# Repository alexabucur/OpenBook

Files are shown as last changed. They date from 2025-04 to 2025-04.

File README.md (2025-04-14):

# OpenBook



## Prezentare generala

Proiectul a fost realizat in cadrul disciplinei _Testarea Sistemelor de Calcul_ si isi propune crearea unui model 3D detaliat pentru o tableta E-Book Reader. Am proiectat atat la nivel de circuit, cat si la nivel de design al produsului, folosind programul _Fusion360_ de la Autodesk.

## Block Diagram


## Bill of Materials
| Device | Description | Datasheet | Price per Unit | Link |
|---|---|---|---|---|
| ADAFRUIT_LEDCHIP-LED0603 | LED | [datasheet](https://ro.mouser.com/datasheet/2/423/LSM0603412V-1379745.pdf) | 1,50 RON | [link](https://ro.mouser.com/ProductDetail/VCC/LSM0603412V?qs=sGAEpiMZZMt82OzCyDsLFG1ehM2%252BdxqbAopHlSxILTc%3D) |
| SJ | SMD solder JUMPER | [datasheet](https://www.farnell.com/datasheets/2813407.pdf) | 0,01 RON | [link](https://ro.farnell.com/panasonic/erj3gey0r00v/res-0r0-0-1w-0603-thick-film/dp/2059527) |
| ESP32_WROVER_EAGLE-LTSPICE_RR0402 | RESISTOR, European symbol | [datasheet](https://www.vishay.com/doc?28700) | 0,941 RON | [link](https://ro.mouser.com/ProductDetail/Vishay-Beyschlag/MCS04020D9101BE000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) |
| 112A-TAAR-R03_ATTEND | Micro SD Card Socket, Push-Push Type, Top Mount, SMT, H=1.83mm, 10u | [datasheet](https://www.attend.com.tw/data/download/file/112A-TAAR-R03.pdf) | 1,54 RON | [link](https://www.soselectronic.com/ro-ro/products/attend/112a-taar-r03-116052) |
| EAGLE-LTSPICE_CC0402 | CAPACITOR, European symbol | [datasheet](https://ro.mouser.com/datasheet/2/40/Accu_P-3077555.pdf) | 5,74 RON | [link](https://ro.mouser.com/ProductDetail/KYOCERA-AVX/04025J0R5ZBSTR?qs=k4kUdCzLgS7v2DzbDWDPRw%3D%3D) |
| ESP32_WROVER_SPARKFUN-DISCRETESEMI_MOSFET_PCH-DMG2305UX-7 | P-channel MOSFETs | [datasheet](https://www.diodes.com/assets/Datasheets/DMG2305UX.pdf) | 0,941 RON | [link](https://ro.mouser.com/ProductDetail/Diodes-Incorporated/DMG2305UX-7?qs=L1DZKBg7t5F%2FNBHrjfxC%252Bg%3D%3D) |
| 744043680IND_4828-WE-TPC_WRE | | [datasheet](https://www.we-online.com/components/products/datasheet/744043680.pdf) | 6,44 RON | [link](https://ro.mouser.com/ProductDetail/Wurth-Elektronik/744043680?qs=PGXP4M47uW6VkZq%252BkzjrHA%3D%3D)|
| BD5229G-TR | Voltage Detector with Adjustable Delay Time | [datasheet](https://datasheet.datasheetarchive.com/originals/distributors/Datasheets_SAMA/f2b9741ef86007909f138d561a359946.pdf) | 3,72 RON | [link](https://ro.mouser.com/ProductDetail/ROHM-Semiconductor/BD5229G-TR?qs=4kLU8WoGk0vvnhrrYwdszw%3D%3D) |
| CPH3225A | Cap 0.011F 3.3V 1210 Flat | [datasheet](https://ro.mouser.com/datasheet/2/360/Seiko_Instruments_MicroBattery_E_20230330_2024Jan_-3561061.pdf) | 11,04 RON | [link](https://ro.mouser.com/ProductDetail/Seiko-Semiconductors/CPH3225A?qs=3etwrb1wR%252BhUOph6lAO7eg%3D%3D) | 
| DS3231SN# | Real Time Clock Serial 16-Pin SOIC W T/R | [datasheet](https://ro.mouser.com/datasheet/2/609/DS3231-3421123.pdf) | 73,80 RON | [link](https://ro.mouser.com/ProductDetail/Analog-Devices-Maxim-Integrated/DS3231SN?qs=1eQvB6Dk1vhUlr8%2FOrV0Fw%3D%3D) |
| ESP32-C6-WROOM-1-N8 | | [datasheet](https://ro.mouser.com/datasheet/2/891/Espressif_ESP32_C6_WROOM_1__Datasheet_V0_1_PRELIMI-3239987.pdf) | 14,70 RON | [link](https://ro.mouser.com/ProductDetail/Espressif-Systems/ESP32-C6-WROOM-1-N8?qs=8Wlm6%252BaMh8ST02Gmwp74cw%3D%3D) |
| ESP32_WROVER_AVX---SD0805S020S1R0_AVX_ SD0805S020S1R0_0_0AVX_SD0805S020S1R0_0_0 | Schottky Barrier Rectifier Diode | [datasheet](http://datasheets.avx.com/schottky.pdf) | 1,46 RON | [link](https://ro.mouser.com/ProductDetail/KYOCERA-AVX/SD0805S020S1R0?qs=jCA%252BPfw4LHbpkAoSnwrdjw%3D%3D) |
| ESP32_WROVER_BME680_BME680 | Integrated Environmental Unit | [datasheet](https://ro.mouser.com/datasheet/2/783/BST_BME680_DS001-1509608.pdf) | 40,69 RON | [link](https://ro.mouser.com/ProductDetail/Bosch-Sensortec/BME680?qs=v271MhAjFHjo0yA%2FC4OnDQ%3D%3D) |
| ESP32_WROVER_SPARKFUN-IC-POWER_MCP73831 | MCP73831T Li-Ion, Li-Pol Controller | [datasheet](https://ro.mouser.com/datasheet/2/268/MCP73831_Family_Data_Sheet_DS20001984H-3441711.pdf) | 3,57 RON | [link](https://ro.mouser.com/ProductDetail/Microchip-Technology/MCP73831T-4ADI-OT?qs=hH%252BOa0VZEiBTiqxSV9eepQ%3D%3D) |
| FH34SRJ-24S-0.5SH_99_ |  (0.50mm) Surface Mount, Right Angle | [datasheet](https://ro.mouser.com/datasheet/2/185/FH34SRJ_24S_0_5SH_99__CL0580_1255_6_99_2DDrawing_0-1615044.pdf) | 12,87 RON | [link](https://ro.mouser.com/ProductDetail/Hirose-Connector/FH34SRJ-24S-0.5SH99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) |
| MAX17048G+T10 |  | [datasheet](https://ro.mouser.com/datasheet/2/609/MAX17048_MAX17049-3469099.pdf) | 21,19 RON | [link](https://ro.mouser.com/ProductDetail/Analog-Devices-Maxim-Integrated/MAX17048G%2bT10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) |
| MBR0530 | ON SEMICONDUCTOR - MBR0530 - DIODE, SCHOTTKY, 0.5A, 30V, SOD-123 | [datasheet](https://www.onsemi.com/PowerSolutions/product.do?id=MBR0530T3G) | 0,89 RON | [link](https://ro.mouser.com/ProductDetail/onsemi/MBR0530T3G?qs=3JMERSakebpEmdUS6GetdQ%3D%3D) |
| PGB1010603MR |  | [datasheet](https://www.littelfuse.com/assetdocs/pulseguard-esd-suppressors-pgb1-datasheet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) | 1,98 RON | [link](https://ro.mouser.com/ProductDetail/Littelfuse/PGB1010603MR?qs=gu7KAQ731URLg4GSnNNN7Q%3D%3D) |
| QWIIC_CONNECTORJS-1MM | SparkFun I2C Standard Qwiic Connector | [datasheet](https://ro.mouser.com/datasheet/2/813/Qwiic_Connector_Datasheet-1223982.pdf) | 2,75 RON | [link](https://ro.mouser.com/ProductDetail/SparkFun/PRT-14417?qs=wd5RIQLrsJhgdz%2FpmZ%2F3GQ%3D%3D) |
| SAMACSYS_PARTS_USB4110-GF-A | CONN USB 2.0 TYPE-C R/A SMT | [datasheet](https://ro.mouser.com/datasheet/2/837/GCT_USB4110_Product_Drawing___20k_cycles-3455479.pdf) | 5,84 RON | [link](https://ro.mouser.com/ProductDetail/GCT/USB4110-GF-A?qs=KUoIvG%2F9IlYiZvIXQjyJeA%3D%3D) |
| SI1308EDL-T1-GE3 | MOSFET N-Ch 30V 1.5A TrenchFET SC70 Vishay Si1308EDL-T1-GE3 N-channel MOSFET Transistor, 1.5 A, 30 V, 3-Pin SC-70 | [datasheet](https://www.vishay.com/doc?63399) | 2,07 RON | [link](https://ro.mouser.com/ProductDetail/Vishay-Semiconductors/SI1308EDL-T1-GE3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) |
| USBLC6-2SC6Y | Low Cap. ESD Protection Auto SOT-23-6 STMicroelectronics  | [datasheet](https://ro.mouser.com/datasheet/2/389/usblc6_2sc6y-1852505.pdf) | 2,16 RON | [link](https://ro.mouser.com/ProductDetail/STMicroelectronics/USBLC6-2SC6Y?qs=gNDSiZmRJS%2FOgDexvXkdow%3D%3D) |
| W25Q512JVEIQ |  | [datasheet](https://ro.mouser.com/datasheet/2/949/Winbond_W25Q512JV_Datasheet-3240039.pdf) | 28,91 RON | [link](https://ro.mouser.com/ProductDetail/Winbond/W25Q512JVEIQ?qs=l7cgNqFNU1jw6svr3at6tA%3D%3D) |
| XC6220A331MR-G | LDO Voltage Regulators | [datasheet](https://ro.mouser.com/datasheet/2/760/xc6220-3371556.pdf) | 7,23 RON | [link](https://ro.mouser.com/ProductDetail/Torex-Semiconductor/XC6220A331MR-G?qs=AsjdqWjXhJ8ZSWznL1J0gg%3D%3D) |

## Functionalitate hardware
Componentele principale ale circuitului sunt:

+ USB C Connector + ESD Protection
  
 > destinat alimentarii E-Book, se conecteaza prin interfata USB
 
+ SD Card
 
 > Secure Digital Card este folosit ca si mediu de stocare pentru cartile in format electronic; lucreaza la 3.3V si se conecteaza cu microcontrollerul prin interfata SPI
 
+ E-Paper Display, impreuna cu modulele aferente - E-Paper Drive Circuit, E-Paper Display Header, EPD Power
  
> EPD Header se conecteaza prin interfata SPI la microcontroller, si realizeaza legatura intre celelalte componente
> EPD Power furnizeaza tensiuni multiple, iar E-Paper Drive Circuit genereaza semnalele necesare pentru controlul display-ului E-Paper
>
> display-ul consuma cel mai mult la refresh, 30mA daca este alb-negru si pana la 60mA pentru display color, iar in modul inactiv, dupa ce a afisat imaginea, consumul este chiar zero
 
+ Environmental Sensor BME688
  
 > este un senzor de mediu ce poate masura temperatura, umiditatea, presiunea atmosferica si calitatea aerului, care functioneaza la 3.3V si se conecteaza prin interfata I2C
>
> are un consum redus, in standby sub 1uA, iar pentru masurare foloseste intre 1-2mA

+ RTC Module DS3231SN
  
 > este un modul Real-Time Clock care are rolul de a pastra data si ora curenta atunci cand microcontroller-ul este oprit; poate functiona pe baterie, si are un cristal de 32KHz integrat; se conecteaza la ESP32-C6 prin I2C, folosind pinii SCL si SDA
>
> consumul sau tipic variaza de la 150uA, atunci cand este alimentat de la sursa principala, si scade la 1uA la trecerea pe baterie

+ External NOR Flash 64MB
  
> extinde memoria microcontroller-ului, aici se stocheaza date suplimentare, se poate face si o stocare temporara; foloseste interfata SPI
> 
> contributia sa la consumul energetic total este foarte mica; cel mai mult se consuma la stergerea din flash (in jur de 50mA), respectiv la scriere (30-50mA); in standby se consuma numai 10-20uA

+	LDO Voltage Regulator
  
> este un stabilizator de tensiune liniar, care asigura tensiunea de iesire constanta la valoarea de 3.3V pentru microcontroller;
>
> are un consum energetic foarte mic (in jur de 8uA atunci cand este activ), ceea ce il face ideal pentru dispozitive alimentate pe baza de baterie, precum cel de fata

+ Voltage Supervisor
  
> folosit pentru monitorizeaza nivelului tensiunii, si pentru a asigura ca sistemul nu poate porni atunci cand avem o tensiune instabila sau mult prea mica

+ Qwiic/Stemma QT
  
> simplifica atasarea senzorilor si perifericelor la microcontroller, facand posibila conectarea mai multor dispozitive in lant, fara a fi nevoie de fire distincte pentru fiecare semnal; functioneaza pe baza protocolului I2C

+ Li-Po Battery Controller

> gestioneaza incarcarea/descarcarea bateriei, regland constant tensiunea si curentul;  la alimentarea bateriei, previne supraincarcarea , iar la descarcare monitorizeaza tensiunea pentru a evita descarcarea profunda; este conectat la sursa de alimentare si la baterie

## Microcontroller - ESP32-C6
Intreg circuitul a fost conceput in jurul microcontrollerului ESP32-C6-WROOM, care este un modul preasamblat, si principalul consumator energetic al circuitului. Consumul mediu se situeaza undeva intre 100uA si 2mA, avand in vedere ca in modul _Activ_ se consuma in jur de 100-120mA, in _Idle_ 10-15mA iar atunci cand se afla in _Deep Sleep_ doar 10-20uA. In mod evident, consumul depinde cel mai mult de durata sesiunilor active.
> Placa ESP-WROOM-32 dispune de o varietate de interfete pentru conectarea altor componente si senzori, inclusiv pini de I/O, SPI, I2C si UART. Aceastea faciliteaza integrarea si extind gama de aplicatii posibile. Placa foloseste WiFi 6 2.4 GHz, are integrat Bluetooth 5 si antena.
>> ESP32_C6
> ESP32-C6 se leaga de cele mai importante module ale circuitului prin intermediul pinilor sai:
> - **Alimentare si reset**
>> **3V3** asigura alimentrea modulului, **GND** legatura la masa, **EN** trebuie sa fie pe pozitia _HIGH_ pentru ca modulul sa functioneze (EN va fi controlat de catre butonul RESET)
> - **USB C Connector**
>> deoarece ESP32-C6 are USB nativ, conexiunea se realizeaza direct prin liniile de date **USB_D+** si **USB_D-**, la pinii **GPIO13** si **GPIO14** ai modulului; nu mai este deci nevoie de un convertor serial extern
> - **SD Card**
>> pentru a comunica cu dispozitive rapide precum SD Card se foloseste interfata SPI(Serial Peripheral Interface), folosind pinii **GPIO27(MISO)** - pentru transfer de la card la ESP, **GPIO7(MOSI)** - pentru transfer invers, **GPIO6(SCK)** -semnalul de ceas care asigura sincronizarea, respectiv **GPIO4(SS_SD)** - chip select
> - **E-Paper Display**
>> pentru conexiunea si controlul ecranului dispozitivului se folosesc pinii **GPIO11(EPD_CS)** - Chip Select pentru display-ul EPD, **GPIO5(EPD_DC)** - pentru controlul display-ului, **GPIO21(EPD_RST)** - pentru resetarea display-ului, respectiv **GPIO26(EPD_BUSY)**
> - **Environmental Sensor BME688**
>> avand in vedere ca se face comunicatia cu senzorul prin intermediul protocolului I2C, pentru stabilirea legaturii se vor folosi pinii **GPIO19(SDA)**, **GPIO20(SCL)** si **GPIO17(I2C_PW)** de pe microcontroller
> - **UART(Serial Communication)**
>> ESP32-C6 are si interfete seriale, utile pentru debugging sau conexiuni cu alte dispozitive; pinii aferenti comunicarii UART sunt **TXD0** -pentru transmisia datelor respectiv **RXD0** - pentru receptie de date
> - **Restul pinilor**
>> - **FLASH_CS** este un pin Chip Select pentru selectarea chipului flash extern (pentru comunicarea SPI cu External NOR Flash)
>> - **IO/BOOT** folosit pentru a intra in boot mode – legatura cu butonul de _boot_
>> - **RTC_PWM** pentru semnale Pulse Width Modulation trimise catre Real Time Clock
>> - **RTC_RST** pentru resetarea ceasului
>> - **INT_RTC** destinat semnalelor de intrerupere de la modulul RTC, de exemplu in cazul iesirii din moduri de functionare (sleep), pentru executarea unor sarcini periodice, cum ar fi un refresh al display-ului etc.

## Amplasarea componentelor / Reguli de design

La design-ul PCB-ului am tinut cont de cateva aspecte importante in ceea ce priveste amplasarea componentelor pe placuta. Astfel:

+ **Microcontroller-ul ESP32** se afla in marginea de sus a PCB-ului, cu antena inspre exterior si cu PCB-ul decupat in aceasta zona, pentru ca antena sa nu fie blocata si pentru a se evita orice interferente
+ **Conectorul USB** se afla in partea de jos a placutei, centrat astfel incat sa se alinieze cu orificiul din carcasa si sa permita conectarea mufei USB-C
+ **E-Paper Display Header** este pozitionat pe lateral, iar in dreptul sau exista un decupaj in PCB - acesta este spatiul in care se va introduce ribbon-ul display-ului nostru
+  **Conectorul Qwiic** e amplasat pe marginea PCB-ului, si s-a lasat suficient spatiu in jurul sau, pentru a permite conectarea facila a unor cabluri suplimentare
+  PCB-ul este decupat intr-o zona suficient de mare in care sa incapa si bateria device-ului
## Errors

La editarea PCB-ului in Fusion 360 am intampinat urmatoarele erori:
errors

Erorile au aparut din cauza dimensiunii gaurilor din mufa USB, asa ca le-am aprobat pe amandoua.

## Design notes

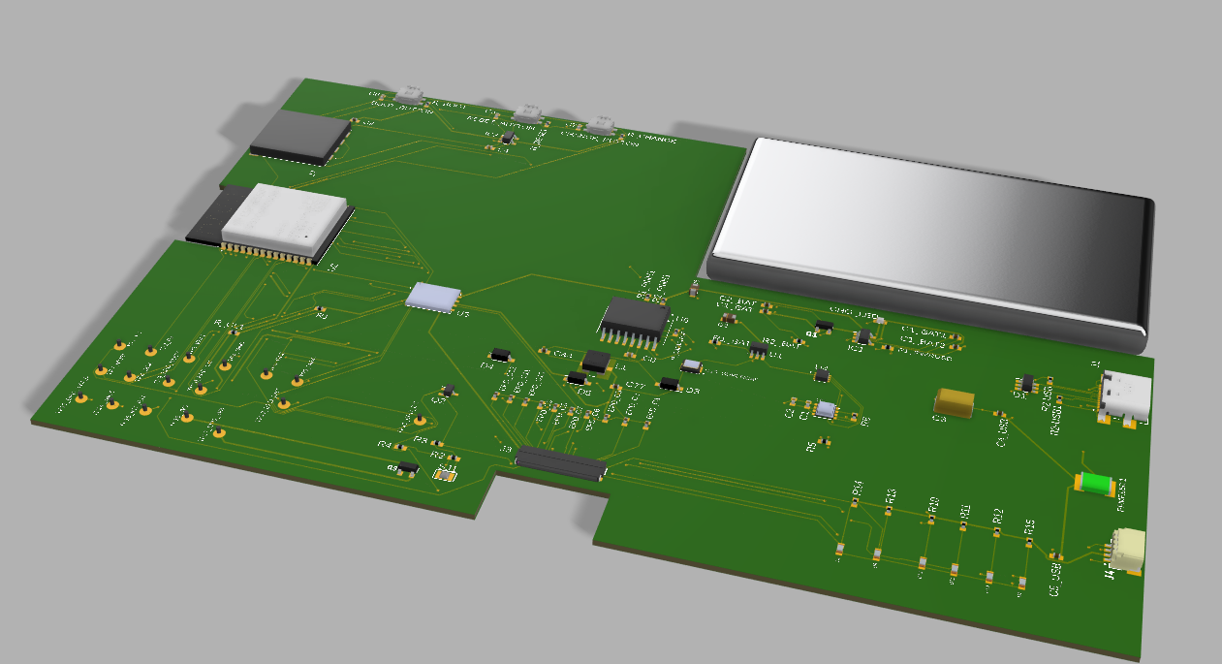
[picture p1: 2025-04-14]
Images/BoardRender.png

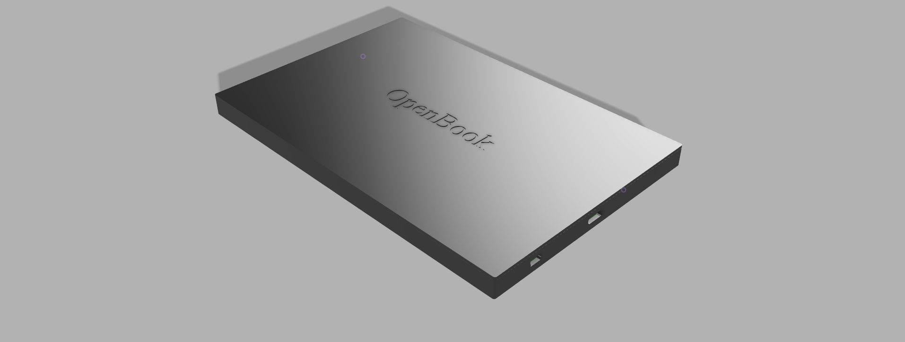
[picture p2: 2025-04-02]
Images/Device.png

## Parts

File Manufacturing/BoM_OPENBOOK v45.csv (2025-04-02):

Qty | Value | Device | Package | Parts | Description | ARROW_PART_NUMBER | ARROW_PRICE-STOCK | AVAILABILITY | CENTROID_NOT_SPECIFIED | CHECK_PRICES | COPYRIGHT | DATASHEET | DESCRIPTION | DIGIKEY_DESCRIPTION | DIGIKEY_PART_NUMBER | HEIGHT | LEAD_FREE | MANUFACTURER_NAME | MANUFACTURER_PART_NUMBER | MF | MFR_NAME | MOUSER_PART_NUMBER | MOUSER_PRICE-STOCK | MOUSER_TESTING_PART_NUMBER | MOUSER_TESTING_PRICE-STOCK | MP | MPN | PACKAGE | POPULARITY | PREFIX | PRICE | PROD_ID | PURCHASE-URL | ROHS | SNAPEDA_LINK | SPICEMODEL | SPICEPREFIX | TEMPERATURE_RANGE_HIGH | TEMPERATURE_RANGE_LOW | TP_SIGNAL_NAME | VALUE
1 |  | ADAFRUIT_LEDCHIP-LED0603 | ADAFRUIT_CHIP-LED0603 | CHG_LED | LED
1 |  | ESP32_WROVER_EAGLE-LTSPICE_RR0402 | ESP32_WROVER_EAGLE-LTSPICE_R0402 | R_CAPACITOR | RESISTOR, European symbol |  |  |  |  |  |  |  |  |  |  |  |  |  |  |  |  |  |  |  |  |  |  |  |  |  |  |  |  |  |  | NONE | R
1 |  | SJ | SJ | SJ1 | SMD solder JUMPER |  |  |  |  |  |  |  |  |  |  |  |  |  |  |  |  |  |  |  |  |  |  |  | 3
1 | 0.1uF/50V | EAGLE-LTSPICE_CC0402 | EAGLE-LTSPICE_C0402 | EPD_C5 | CAPACITOR, European symbol |  |  |  |  |  |  |  |  |  |  |  |  |  |  |  |  |  |  |  |  |  |  |  |  |  |  |  |  |  |  | NONE | C
1 | 0.47 | ESP32_WROVER_EAGLE-LTSPICE_RR0402 | ESP32_WROVER_EAGLE-LTSPICE_R0402 | R3 | RESISTOR, European symbol |  |  |  |  |  |  |  |  |  |  |  |  |  |  |  |  |  |  |  |  |  |  |  |  |  |  |  |  |  |  | NONE | R
1 | 100K | ESP32_WROVER_EAGLE-LTSPICE_RR0402 | ESP32_WROVER_EAGLE-LTSPICE_R0402 | R1_PWRUSB | RESISTOR, European symbol |  |  |  |  |  |  |  |  |  |  |  |  |  |  |  |  |  |  |  |  |  |  |  |  |  |  |  |  |  |  | NONE | R
8 | 100nF | EAGLE-LTSPICE_CC0402 | EAGLE-LTSPICE_C0402 | C1, C2, C4, C4_USB, C6, C7, C8, C9 | CAPACITOR, European symbol |  |  |  |  |  |  |  |  |  |  |  |  |  |  |  |  |  |  |  |  |  |  |  |  |  |  |  |  |  |  | NONE | C
1 | 100uF | RCL_CPOL-EUCT3528 | RCL_CT3528 | C3 | POLARIZED CAPACITOR, European symbol |  |  |  |  |  |  |  |  |  |  |  |  |  |  |  |  |  |  |  |  |  |  |  | 0 |  |  |  |  |  |  |  | C
16 | 10K | ESP32_WROVER_EAGLE-LTSPICE_RR0402 | ESP32_WROVER_EAGLE-LTSPICE_R0402 | R1, R1_PINH1, R2_PINH1, R4, R5, R6, R10, R11, R12, R13, R14, R15, R_BOOT, R_CHANGE, R_CL1, R_RESET | RESISTOR, European symbol |  |  |  |  |  |  |  |  |  |  |  |  |  |  |  |  |  |  |  |  |  |  |  |  |  |  |  |  |  |  | NONE | R
1 | 10uF | EAGLE-LTSPICE_CC0402 | EAGLE-LTSPICE_C0402 | C77 | CAPACITOR, European symbol |  |  |  |  |  |  |  |  |  |  |  |  |  |  |  |  |  |  |  |  |  |  |  |  |  |  |  |  |  |  | NONE | C
1 | 112A-TAAR-R03_ATTEND | 112A-TAAR-R03_ATTEND | 112ATAARR03ATTEND | J2 | Micro SD Card Socket, Push-Push Type, Top Mount, SMT, H=1.83mm, 10u |  |  |  |  |  |  |  | Micro SD Card Socket | Push-Push Type | Top Mount | SMT | H=1.83mm | 10u |  |  | 1.9mm |  | ATTEND | 112A-TAAR-R03 ATTEND
1 | 1uF | EAGLE-LTSPICE_CC0402 | EAGLE-LTSPICE_C0402 | C5 | CAPACITOR, European symbol |  |  |  |  |  |  |  |  |  |  |  |  |  |  |  |  |  |  |  |  |  |  |  |  |  |  |  |  |  |  | NONE | C
9 | 1uF/50V | EAGLE-LTSPICE_CC0402 | EAGLE-LTSPICE_C0402 | EPD_C1, EPD_C2, EPD_C6, EPD_C7, EPD_C8, EPD_C9, EPD_C10, EPD_C11, EPD_C12 | CAPACITOR, European symbol |  |  |  |  |  |  |  |  |  |  |  |  |  |  |  |  |  |  |  |  |  |  |  |  |  |  |  |  |  |  | NONE | C
1 | 2.2 | ESP32_WROVER_EAGLE-LTSPICE_RR0402 | ESP32_WROVER_EAGLE-LTSPICE_R0402 | R2 | RESISTOR, European symbol |  |  |  |  |  |  |  |  |  |  |  |  |  |  |  |  |  |  |  |  |  |  |  |  |  |  |  |  |  |  | NONE | R
1 | 200 | ESP32_WROVER_EAGLE-LTSPICE_RR0402 | ESP32_WROVER_EAGLE-LTSPICE_R0402 | R1_BAT | RESISTOR, European symbol |  |  |  |  |  |  |  |  |  |  |  |  |  |  |  |  |  |  |  |  |  |  |  |  |  |  |  |  |  |  | NONE | R
2 | 20V/4.2A/52mO/1.4W | ESP32_WROVER_SPARKFUN-DISCRETESEMI_MOSFET_PCH-DMG2305UX-7 | ESP32_WROVER_SPARKFUN-DISCRETESEMI_SOT23-3 | Q1, Q3 | P-channel MOSFETs |  |  |  |  |  |  |  |  |  |  |  |  |  |  |  |  |  |  |  |  |  |  |  |  |  |  | TRAN-14388 |  |  |  |  |  |  |  |  | 20V/4.2A/52mO/1.4W
1 | 2K | ESP32_WROVER_EAGLE-LTSPICE_RR0402 | ESP32_WROVER_EAGLE-LTSPICE_R0402 | R2_BAT | RESISTOR, European symbol |  |  |  |  |  |  |  |  |  |  |  |  |  |  |  |  |  |  |  |  |  |  |  |  |  |  |  |  |  |  | NONE | R
5 | 4.7uF | EAGLE-LTSPICE_CC0402 | EAGLE-LTSPICE_C0402 | C1_BAT, C1_BAT1, C1_BAT2, C2_BAT, C5_USB | CAPACITOR, European symbol |  |  |  |  |  |  |  |  |  |  |  |  |  |  |  |  |  |  |  |  |  |  |  |  |  |  |  |  |  |  | NONE | C
1 | 4.7uF/25V | EAGLE-LTSPICE_CC0402 | EAGLE-LTSPICE_C0402 | C44 | CAPACITOR, European symbol |  |  |  |  |  |  |  |  |  |  |  |  |  |  |  |  |  |  |  |  |  |  |  |  |  |  |  |  |  |  | NONE | C
2 | 5k1 | ESP32_WROVER_EAGLE-LTSPICE_RR0402 | ESP32_WROVER_EAGLE-LTSPICE_R0402 | R2-USB, R2-USB1 | RESISTOR, European symbol |  |  |  |  |  |  |  |  |  |  |  |  |  |  |  |  |  |  |  |  |  |  |  |  |  |  |  |  |  |  | NONE | R
1 | 68uH | 744043680IND_4828-WE-TPC_WRE | IND_4828-WE-TPC_WRE | L1 |  |  |  |  |  |  | Copyright (C) 2024 Ultra Librarian. All rights reserved. |  |  |  |  |  |  |  | 744043680 |  | Wurth Electronics
1 | BD5229G-TR | BD5229G-TR | SOT95P280X125-5N | IC2 | Voltage Detector with Adjustable Delay Time: CMOS processes are utilized to develop high precision, low current consumption CMOS reset ICs that allow arbitrary setting of the delay time. The extensive lineup includes both Nch Open Drain and CMOS output types in a wide range of detection voltages (from 2.3V to 6.0V, in 0.1V steps), enabling selection of the ideal solution based on customer requirements. In addition, the entire series is of course both lead-free and RoHS-compliant. |  |  |  |  |  |  |  | Voltage Detector with Adjustable Delay Time: CMOS processes are utilized to develop high precision | low current consumption CMOS reset ICs that allow arbitrary setting of the delay time. The extensive lineup includes both Nch Open Drain and CMOS output types in a wide range of detection voltages (from 2.3V to 6.0V | in 0.1V steps) | enabling selection of the ideal solution based on customer requirements. In addition | the entire series is of course both lead-free and RoHS-compliant. |  |  | 1.25mm |  | ROHM Semiconductor | BD5229G-TR |  |  | 755-BD5229G-TR | https://www.mouser.co.uk/ProductDetail/ROHM-Semiconductor/BD5229G-TR?qs=4kLU8WoGk0vvnhrrYwdszw%3D%3D
3 | BUTTON_CUSYOMV1 | BUTTON_CUSYOMV1 | MYBUTTON | BOOT_BUTTON, CHANGE_BUTTON, RESET_BUTTON
1 | CPH3225A | CPH3225A | CAPCP3225X100N | C10_SUPERCAP | Cap 0.011F 3.3V 1210 Flat Check availability |  |  | Not in stock |  | https://www.snapeda.com/parts/CPH3225A/Seiko+Instruments/view-part/?ref=eda |  |  | 11 mF (EDLC) Supercapacitor 3.3 V 1210 (3225 Metric) - - |  |  |  |  |  |  | Seiko Instruments |  |  |  |  |  | CPH3225A |  | 1210 Seiko |  |  | None |  | https://www.snapeda.com/api/url_track_click_mouser/?unipart_id=562593&manufacturer=Seiko Instruments&part_name=CPH3225A&search_term=None |  | https://www.snapeda.com/parts/CPH3225A/Seiko+Instruments/view-part/?ref=snap
1 | DS3231SN# | DS3231SN# | SOIC127P1032X265-16N | U6 | Real Time Clock Serial 16-Pin SOIC W T/R Check availability |  |  | In Stock |  | https://www.snapeda.com/parts/DS3231SN%23/Analog+Devices/view-part/?ref=eda |  |  | Extremely Accurate I²C-Integrated RTC/TCXO/Crystal |  |  |  |  |  |  | Analog Devices |  |  |  |  |  | DS3231SN# |  | SOIC-16 Maxim |  |  | None |  | https://www.snapeda.com/api/url_track_click_mouser/?unipart_id=99048&manufacturer=Analog Devices&part_name=DS3231SN#&search_term=None |  | https://www.snapeda.com/parts/DS3231SN%23/Analog+Devices/view-part/?ref=snap
1 | ESP32-C6-WROOM-1-N8 | ESP32-C6-WROOM-1-N8 | XCVR_ESP32-C6-WROOM-1-N8 | U2 | Check availability |  |  | In Stock |  | https://www.snapeda.com/parts/ESP32-C6-WROOM-1-N8/Espressif+Systems/view-part/?ref=eda |  |  | Multiprotocol Modules ESP32-C6 module | Wi-Fi 6 in 2.4 GHz band | Bluetooth 5 | Zigbee 3.0 and Thread. ESP34-WROOM Compatible - ENGINEERING SAMPLE |  |  |  |  |  |  | Espressif Systems |  |  |  |  |  | ESP32-C6-WROOM-1-N8 |  | None |  |  | None |  |  |  | https://www.snapeda.com/parts/ESP32-C6-WROOM-1-N8/Espressif+Systems/view-part/?ref=snap
1 | ESP32C6_VARISTORCN1812 | ESP32C6_VARISTORCN1812 | ESP32C6_VARISTOR_CT/CN1812 | PFMF.050.1 | VARISTOR |  |  |  |  |  |  |  |  |  |  |  |  |  |  |  |  |  |  |  |  |  |  |  | 0
2 | ESP32_WROVER_AVX---SD0805S020S1R0_AVX_SD0805S020S1R0_0_0AVX_SD0805S020S1R0_0_0 | ESP32_WROVER_AVX---SD0805S020S1R0_AVX_SD0805S020S1R0_0_0AVX_SD0805S020S1R0_0_0 | ESP32_WROVER_AVX---SD0805S020S1R0_AVX_SD0805S020S1R0_0 | D2, D6 | Schottky Barrier Rectifier Diode |  |  |  | No |  |  | http://datasheets.avx.com/schottky.pdf |  | DIODE SCHOTTKY 20V 1A 0805 | 478-7800-1-ND |  | yes |  |  | AVX |  | 581-SD0805S020S1R0 |  |  |  |  |  | 0805 (2012 metric) |  | D |  |  |  | yes |  |  |  | +125°C | -55°C
1 | ESP32_WROVER_BME680_BME680 | ESP32_WROVER_BME680_BME680 | ESP32_WROVER_BME680_PSON80P300X300X100-8N | U3 | Integrated Environmental Unit |  |  | Unavailable |  |  |  |  | Integrated Environmental Unit |  |  |  |  |  |  | Bosch Sensortec |  |  |  |  |  | BME680 |  | LGA-8 Bosch Tools |  |  | None
1 | ESP32_WROVER_SPARKFUN-IC-POWER_MCP73831 | ESP32_WROVER_SPARKFUN-IC-POWER_MCP73831 | ESP32_WROVER_SPARKFUN-IC-POWER_SOT23-5 | U1 | MCP73831T Li-Ion, Li-Pol Controller |  |  |  |  |  |  |  |  |  |  |  |  |  |  |  |  |  |  |  |  |  |  |  |  |  |  | IC-09995
1 | FH34SRJ-24S-0.5SH_99_ | FH34SRJ-24S-0.5SH_99_ | FH34SRJ24S05SH99 | J3 | (0.50mm) Surface Mount, Right Angle |  |  |  |  |  |  |  | 24 Position FFC | FPC Connector Contacts | (0.50mm) Surface Mount | Right Angle |  |  | 1.1mm |  | Hirose | FH34SRJ-24S-0.5SH(99) |  |  | 798-FH34SRJ24S05SH99 | https://www.mouser.co.uk/ProductDetail/Hirose-Connector/FH34SRJ-24S-0.5SH99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
1 | MAX17048G+T10 | MAX17048G+T10 | SON50P200X200X80-9N | U4 | Check availability |  |  | In Stock |  | https://www.snapeda.com/parts/MAX17048G+T10/Analog+Devices/view-part/?ref=eda |  |  | 3µA 1-Cell/2-Cell Fuel Gauge with ModelGauge |  |  |  |  |  |  | Analog Devices |  |  |  |  |  | MAX17048G+T10 |  | TDFN-8 Maxim |  |  | None |  | https://www.snapeda.com/api/url_track_click_mouser/?unipart_id=329239&manufacturer=Analog Devices&part_name=MAX17048G+T10&search_term=None |  | https://www.snapeda.com/parts/MAX17048G+T10/Analog+Devices/view-part/?ref=snap
3 | MBR0530 | MBR0530 | SOD3716X135N | D3, D4, D5 | ON SEMICONDUCTOR - MBR0530 - DIODE, SCHOTTKY, 0.5A, 30V, SOD-123 |  |  | In Stock |  | https://www.snapeda.com/parts/MBR0530/Onsemi/view-part/?ref=eda |  |  | Diode Schottky 30 V 500mA Surface Mount SOD-123 |  |  |  |  |  |  | ON Semiconductor |  |  |  |  |  | MBR0530 |  | SOD-123-2 ON Semiconductor |  |  | None |  | https://www.snapeda.com/api/url_track_click_mouser/?unipart_id=179458&manufacturer=ON Semiconductor&part_name=MBR0530&search_term=None |  | https://www.snapeda.com/parts/MBR0530/Onsemi/view-part/?ref=snap
6 | PGB1010603MR | PGB1010603MR | DIOC1608X36N | D7, D8, D9, D10, D11, D12 | Check availability |  |  | In Stock |  | https://www.snapeda.com/parts/PGB1010603MR/Littelfuse/view-part/?ref=eda |  |  | 150V (Typ) Clamp - Ipp Tvs Diode Surface Mount 0603 (1608 Metric) |  |  |  |  |  |  | Littelfuse Inc. |  |  |  |  |  | PGB1010603MR |  | 0603 Littelfuse Inc. |  |  | None |  | https://www.snapeda.com/api/url_track_click_mouser/?unipart_id=5659453&manufacturer=Littelfuse Inc.&part_name=PGB1010603MR&search_term=None |  | https://www.snapeda.com/parts/PGB1010603MR/Littelfuse/view-part/?ref=snap
1 | QWIIC_RIGHT_ANGLE | QWIIC_CONNECTORJS-1MM | JST04_1MM_RA | J4 | SparkFun I2C Standard Qwiic Connector |  |  |  |  |  |  |  |  |  |  |  |  |  |  |  |  |  |  |  |  |  |  |  |  |  |  | CONN-13694 |  |  |  |  |  |  |  |  | QWIIC_RIGHT_ANGLE
1 | SAMACSYS_PARTS_USB4110-GF-A | SAMACSYS_PARTS_USB4110-GF-A | SAMACSYS_PARTS_USB4110GFA | J1 | CONN USB 2.0 TYPE-C R/A SMT |  |  |  |  |  |  |  | CONN USB 2.0 TYPE-C R/A SMT |  |  | 3.26mm |  | GCT (GLOBAL CONNECTOR TECHNOLOGY) | USB4110-GF-A |  |  | 640-USB4110-GF-A | https://www.mouser.co.uk/ProductDetail/GCT/USB4110-GF-A?qs=KUoIvG%2F9IlYiZvIXQjyJeA%3D%3D
1 | SI1308EDL-T1-GE3 | SI1308EDL-T1-GE3 | SOT65P210X110-3N | Q2 | MOSFET N-Ch 30V 1.5A TrenchFET SC70 Vishay Si1308EDL-T1-GE3 N-channel MOSFET Transistor, 1.5 A, 30 V, 3-Pin SC-70 |  |  | In Stock |  | https://www.snapeda.com/parts/SI1308EDL-T1-GE3/Vishay+Siliconix/view-part/?ref=eda |  |  | Si1308EDL-T1-GE3 N-channel MOSFET Transistor | 1.5 A | 30 V | 3-Pin SC-70 | Siliconix / Vishay SI1308EDL-T1-GE3 |  |  |  |  |  |  | Vishay Siliconix |  |  |  |  |  | SI1308EDL-T1-GE3 |  | SOT-323 Vishay Semiconductor |  |  | None |  | https://www.snapeda.com/api/url_track_click_mouser/?unipart_id=274603&manufacturer=Vishay Siliconix&part_name=SI1308EDL-T1-GE3&search_term=None |  | https://www.snapeda.com/parts/SI1308EDL-T1-GE3/Vishay+Siliconix/view-part/?ref=snap
17 | TPTP20R | TPTP20R | TP20R | TP1, TP2, TP3, TP4, TP5, TP6, TP7, TP8, TP9, TP10, TP11, TP12, TP13, TP14, TP15, TP16, TP17 | Test pad |  |  |  |  |  |  |  |  |  |  |  |  |  |  |  |  |  |  |  |  |  |  |  | 2
1 | USBLC6-2SC6Y | USBLC6-2SC6Y | SOT95P280X145-6N | D1 | Low Cap. ESD Protection Auto SOT-23-6 STMicroelectronics USBLC6-2SC6Y, Dual Uni-Directional TVS Diode Array, 6-Pin SOT-23 |  |  | In Stock |  | https://www.snapeda.com/parts/USBLC6-2SC6Y/STMicroelectronics/view-part/?ref=eda |  |  | 17V Clamp 5A (8/20µs) Ipp Tvs Diode Surface Mount SOT-23-6 |  |  |  |  |  |  | STMicroelectronics |  |  |  |  |  | USBLC6-2SC6Y |  | SOT-23-6 STMicroelectronics |  |  | None |  |  |  | https://www.snapeda.com/parts/USBLC6-2SC6Y/STMicroelectronics/view-part/?ref=snap
1 | W25Q512JVEIQ | W25Q512JVEIQ | SON127P600X800X80-9N | U5 | Check availability |  |  | In Stock |  | https://www.snapeda.com/parts/W25Q512JVEIQ/Winbond+Electronics/view-part/?ref=eda |  |  | FLASH - NOR Memory IC 512Mb (64M x 8) SPI - Quad I/O 133 MHz 8-WSON (8x6) |  |  |  |  |  |  | Winbond Electronics |  |  |  |  |  | W25Q512JVEIQ |  | Package |  |  | None |  |  |  | https://www.snapeda.com/parts/W25Q512JVEIQ/Winbond+Electronics/view-part/?ref=snap
1 | XC6220A331MR-G | XC6220A331MR-G | SOT95P280X120-5N | IC1 | LDO Voltage Regulators |  |  |  |  |  |  |  | LDO Voltage Regulators |  |  | 1.2mm |  | Torex | XC6220A331MR-G |  |  | 865-XC6220A331MR-G | https://www.mouser.co.uk/ProductDetail/Torex-Semiconductor/XC6220A331MR-G?qs=AsjdqWjXhJ8ZSWznL1J0gg%3D%3D

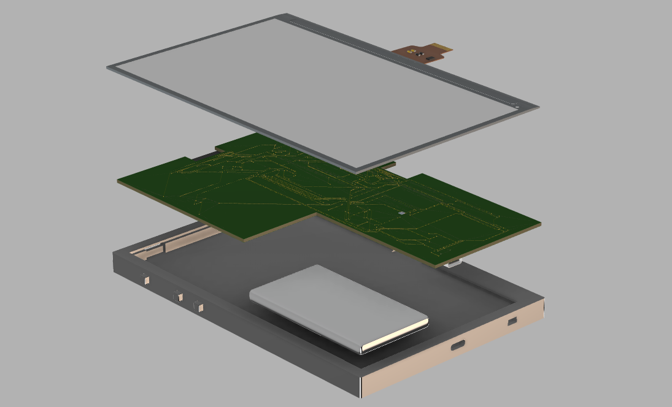
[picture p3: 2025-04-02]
Images/All_Components_Exploded.png

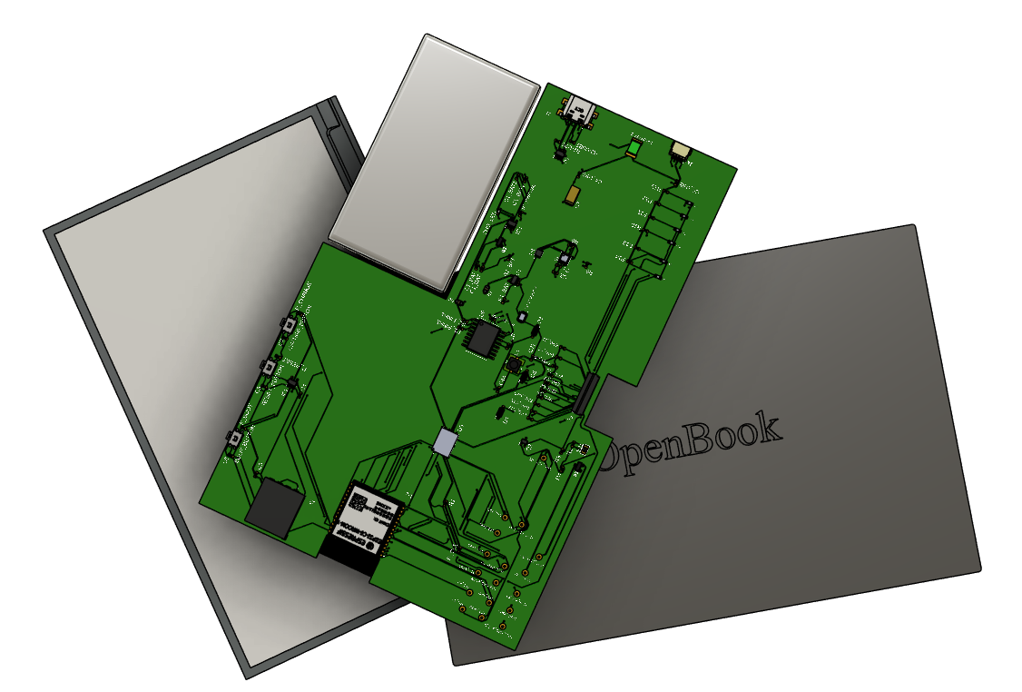
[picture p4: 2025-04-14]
Images/All_Components.png

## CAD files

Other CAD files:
Mechanical/OPENBOOK_3D_EXPLODED.step
Mechanical/OPENBOOK_3D_FINAL.f3z

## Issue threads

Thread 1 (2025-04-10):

[3D] Lipsă elemente 3D

anamariapotoceanu, 2025-04-10:
Lipsesc componente 3D printre care componenta **U3** (DS3231SN#), condensatori, componenta **J3 (QWIIC_RIGHT_ANGLE)**, componenta **SJ1**, **U2**, componenta **J1**.

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

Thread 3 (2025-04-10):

[PCB] Plasarea componentelor într-un mod necorespunzător

anamariapotoceanu, 2025-04-10:
În anumite zone, componentele par a fi plasate fără o structură clară, ceea ce poate afecta lizibilitatea. Ar fi utilă o organizare mai logică, prin gruparea elementelor.

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

anamariapotoceanu, 2025-04-10:
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

Closed 2025-04-14.

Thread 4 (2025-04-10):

[PCB] Numele componentelor greu de citit

anamariapotoceanu, 2025-04-10:
Numele componentelor sunt dificil de citit, întrucât sunt plasate prea aproape unele de altele, iar spațiul alocat fiecărui element pare insuficient. Ar fi recomandat să se acorde mai mult spațiu între denumiri, fie prin ajustarea dimensiunii fontului, fie prin repoziționarea numelor componentelor, pentru a asigura o prezentare lizibilă.

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

Closed 2025-04-14.

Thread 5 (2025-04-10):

[SCHEMATIC] Aspect schematic

anamariapotoceanu, 2025-04-10:
Lipsesc liniile de separare, ceea ce îngreunează urmărirea schemei electrice. În plus, fontul utilizat pentru etichete este disproporționat față de spațiul disponibil, ceea ce duce la suprapuneri și afectează claritatea schemei.
Recomand utilizarea unui font mai mic și trasarea unor linii (de separare) pentru o mai bună lizibilitate și o organizare mai aerisită a schemei.

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

alexabucur, 2025-04-14:
Am adaugat liniile pentru separare

Closed 2025-04-14.

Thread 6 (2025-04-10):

[SCHEMATIC] Inversare condensator

anamariapotoceanu, 2025-04-10:
Condensatorii sunt inversați în anumite zone.  Aceștia ar trebui rotiți astfel încât să respecte ordinea pinilor.

Te poți ghida după valorile atributelor SpiceOrder1 și SpiceOrder2, care indică direcția corectă de conectare a pinilor. De asemenea, îți recomand să dai zoom pe schema electrică disponibilă pe OCW pentru a compara.

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

VS

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

Closed 2025-04-14.

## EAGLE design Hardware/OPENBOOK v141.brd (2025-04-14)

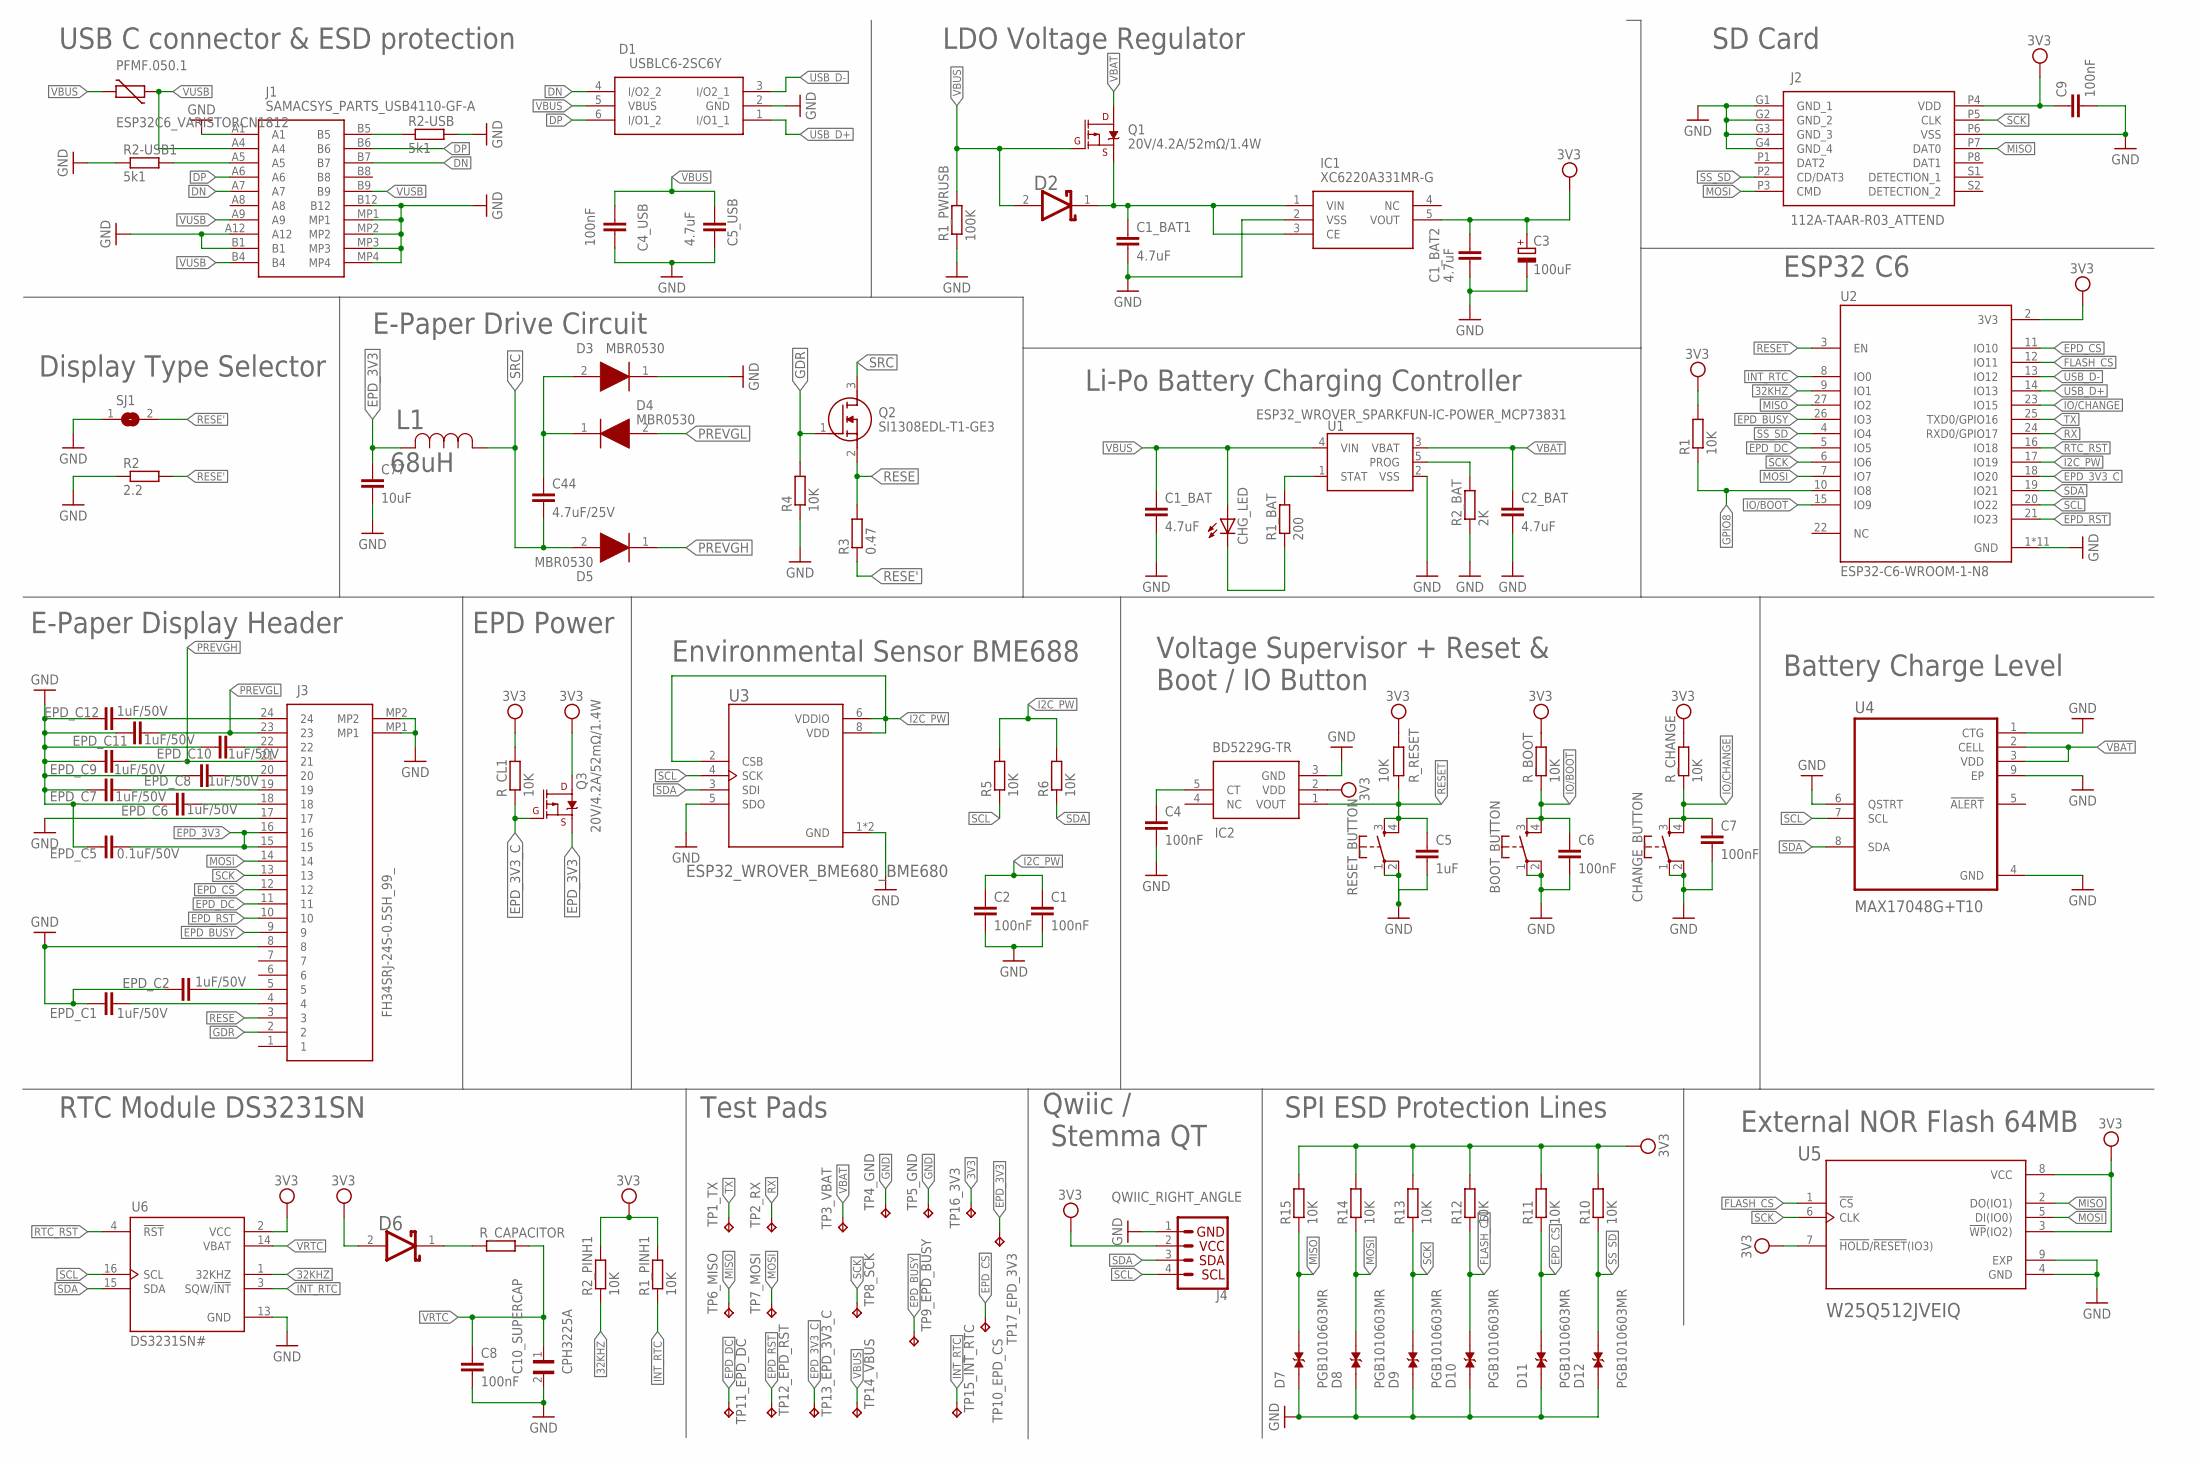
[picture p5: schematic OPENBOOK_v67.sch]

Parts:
BOOT_BUTTON: BUTTON_CUSYOMV1; MYBUTTON
C1, C2, C4, C4_USB, C6, C7, C8, C9: 100nF; EAGLE-LTSPICE_C0402
C1_BAT, C1_BAT1, C1_BAT2, C2_BAT, C5_USB: 4.7uF; EAGLE-LTSPICE_C0402
C3: 100uF; RCL_CT3528
C5: 1uF; EAGLE-LTSPICE_C0402
C10_SUPERCAP: CPH3225A; CAPCP3225X100N
C44: 4.7uF/25V; EAGLE-LTSPICE_C0402
C77: 10uF; EAGLE-LTSPICE_C0402
CHANGE_BUTTON: BUTTON_CUSYOMV1; MYBUTTON
CHG_LED: ADAFRUIT_LEDCHIP-LED0603; ADAFRUIT_CHIP-LED0603
D1: USBLC6-2SC6Y; SOT95P280X145-6N
D2, D6: ESP32_WROVER_AVX---SD0805S020S1R0_AVX_SD0805S020S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; ESP32_WROVER_AVX---SD0805S020S1R0_AVX_SD0805S020S1R0_0
D3, D4, D5: MBR0530; SOD3716X135N
D7, D8, D9, D10, D11, D12: PGB1010603MR; DIOC1608X36N
EPD_C1, EPD_C2, EPD_C6, EPD_C7, EPD_C8, EPD_C9, EPD_C10, EPD_C11, EPD_C12: 1uF/50V; EAGLE-LTSPICE_C0402
EPD_C5: 0.1uF/50V; EAGLE-LTSPICE_C0402
IC1: XC6220A331MR-G; SOT95P280X120-5N
IC2: BD5229G-TR; SOT95P280X125-5N
J1: SAMACSYS_PARTS_USB4110-GF-A; SAMACSYS_PARTS_USB4110GFA
J2: 112A-TAAR-R03_ATTEND; 112ATAARR03ATTEND
J3: FH34SRJ-24S-0.5SH_99_; FH34SRJ24S05SH99
J4: QWIIC_RIGHT_ANGLE; JST04_1MM_RA
L1: 68uH; IND_4828-WE-TPC_WRE
PFMF.050.1: ESP32C6_VARISTORCN1812; ESP32C6_VARISTOR_CT/CN1812
Q1, Q3: 20V/4.2A/52mΩ/1.4W; ESP32_WROVER_SPARKFUN-DISCRETESEMI_SOT23-3
Q2: SI1308EDL-T1-GE3; SOT65P210X110-3N
R1, R1_PINH1, R2_PINH1, R4, R5, R6, R10, R11, R12, R13, R14, R15: 10K; ESP32_WROVER_EAGLE-LTSPICE_R0402
R1_BAT: 200; ESP32_WROVER_EAGLE-LTSPICE_R0402
R1_PWRUSB: 100K; ESP32_WROVER_EAGLE-LTSPICE_R0402
R2: 2.2; ESP32_WROVER_EAGLE-LTSPICE_R0402
R2-USB, R2-USB1: 5k1; ESP32_WROVER_EAGLE-LTSPICE_R0402
R2_BAT: 2K; ESP32_WROVER_EAGLE-LTSPICE_R0402
R3: 0.47; ESP32_WROVER_EAGLE-LTSPICE_R0402
RESET_BUTTON: BUTTON_CUSYOMV1; MYBUTTON
R_BOOT: 10K; ESP32_WROVER_EAGLE-LTSPICE_R0402
R_CAPACITOR: ESP32_WROVER_EAGLE-LTSPICE_RR0402; ESP32_WROVER_EAGLE-LTSPICE_R0402
R_CHANGE: 10K; ESP32_WROVER_EAGLE-LTSPICE_R0402
R_CL1: 10K; ESP32_WROVER_EAGLE-LTSPICE_R0402
R_RESET: 10K; ESP32_WROVER_EAGLE-LTSPICE_R0402
SJ1: SJ
TP1_TX, TP2_RX, TP3_VBAT, TP4_GND, TP5_GND, TP6_MISO, TP7_MOSI, TP8_SCK, TP9_EPD_BUSY, TP10_EPD_CS, TP11_EPD_DC, TP12_EPD_RST, TP13_EPD_3V3_C, TP14_VBUS, TP15_INT_RTC, TP16_3V3, TP17_EPD_3V3: TPTP20R; TP20R
U1: ESP32_WROVER_SPARKFUN-IC-POWER_MCP73831; ESP32_WROVER_SPARKFUN-IC-POWER_SOT23-5
U2: ESP32-C6-WROOM-1-N8; XCVR_ESP32-C6-WROOM-1-N8
U3: ESP32_WROVER_BME680_BME680; ESP32_WROVER_BME680_PSON80P300X300X100-8N
U4: MAX17048G+T10; SON50P200X200X80-9N
U5: W25Q512JVEIQ; SON127P600X800X80-9N
U6: DS3231SN#; SOIC127P1032X265-16N

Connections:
3V3: C1_BAT2.1, C3.+, C9.1, D6.2 (ANODE), IC1.5 (VOUT), IC2.2 (VDD), J2.P4 (VDD), J4.2, Q3.3 (D), R1.2, R1_PINH1.2, R2_PINH1.2, R10.2, R11.2, R12.2, R13.2, R14.2, R15.2, R_BOOT.2, R_CHANGE.2, R_CL1.2, TP16_3V3.TP, U2.2 (3V3), U5.3 (!WP!(IO2)), U5.7 (!HOLD!/!RESET!(IO3)), U5.8 (VCC), U6.2 (VCC)
32KHZ: R2_PINH1.1, U2.9 (IO1), U6.1 (32KHZ)
DN: D1.4 (I/O2_2), J1.A7, J1.B7
DP: D1.6 (I/O1_2), J1.A6, J1.B6
EPD_3V3: C77.1, EPD_C5.1, J3.15, J3.16, L1.2, Q3.2 (S), TP17_EPD_3V3.TP
EPD_3V3_C: Q3.1 (G), R_CL1.1, TP13_EPD_3V3_C.TP, U2.18 (IO20)
EPD_BUSY: J3.9, TP9_EPD_BUSY.TP, U2.26 (IO3)
EPD_CS: D11.2, J3.12, R11.1, TP10_EPD_CS.TP, U2.11 (IO10)
EPD_DC: J3.11, TP11_EPD_DC.TP, U2.5 (IO5)
EPD_RST: J3.10, TP12_EPD_RST.TP, U2.21 (IO23)
FLASH_CS: D10.2, R12.1, U2.12 (IO11), U5.1 (!CS)
GDR: J3.2, Q2.1 (G), R4.2
GND: BOOT_BUTTON.1, BOOT_BUTTON.2, C1.2, C1_BAT.2, C1_BAT1.2, C1_BAT2.2, C2.2, C2_BAT.2, C3.-, C4.2, C4_USB.2, C5.2, C5_USB.2, C6.2, C7.2, C8.2, C9.2, C10_SUPERCAP.2, C77.2, CHANGE_BUTTON.1, CHANGE_BUTTON.2, D1.2 (GND), D3.1 (K), D7.1, D8.1, D9.1, D10.1, D11.1, D12.1, EPD_C1.2, EPD_C2.2, EPD_C5.2, EPD_C6.2, EPD_C7.2, EPD_C8.2, EPD_C9.2, EPD_C10.2, EPD_C11.2, EPD_C12.2, IC1.2 (VSS), IC2.3 (GND), J1.A1, J1.A12, J1.B1, J1.B12, J1.MP1, J1.MP2, J1.MP3, J1.MP4, J2.G1 (GND_1), J2.G2 (GND_2), J2.G3 (GND_3), J2.G4 (GND_4), J2.P6 (VSS), J3.8, J3.17, J3.MP1, J3.MP2, J4.1, R1_PWRUSB.1, R2.1, R2-USB.2, R2-USB1.1, R2_BAT.1, R4.1, RESET_BUTTON.1, RESET_BUTTON.2, SJ1.1, TP4_GND.TP, TP5_GND.TP, U1.2 (VSS), U2.1 (GND), U2.28 (GND), U2.29_1 (GND), U2.29_2 (GND), U2.29_3 (GND), U2.29_4 (GND), U2.29_5 (GND), U2.29_6 (GND), U2.29_7 (GND), U2.29_8 (GND), U2.29_9 (GND), U3.1 (GND), U3.5 (SDO), U3.7 (GND), U4.1 (CTG), U4.4 (GND), U4.6 (QSTRT), U4.9 (EP), U5.4 (GND), U5.9 (EXP), U6.13 (GND)
GPIO8: R1.1, U2.10 (IO8)
I2C_PW: C1.1, C2.1, R5.2, R6.2, U2.17 (IO19), U3.2 (CSB), U3.6 (VDDIO), U3.8 (VDD)
INT_RTC: R1_PINH1.1, TP15_INT_RTC.TP, U2.8 (IO0), U6.3 (SQW/!INT)
IO/BOOT: BOOT_BUTTON.3, BOOT_BUTTON.4, C6.1, R_BOOT.1, U2.15 (IO9)
IO/CHANGE: C7.1, CHANGE_BUTTON.3, CHANGE_BUTTON.4, R_CHANGE.1, U2.23 (IO15)
MISO: D7.2, J2.P7 (DAT0), R15.1, TP6_MISO.TP, U2.27 (IO2), U5.2 (DO(IO1))
MOSI: D8.2, J2.P3 (CMD), J3.14, R14.1, TP7_MOSI.TP, U2.7 (IO7), U5.5 (DI(IO0))
unnamed: J1.B5, R2-USB.1
unnamed: C1_BAT1.1, D2.1 (CATHODE), IC1.1 (VIN), IC1.3 (CE), Q1.2 (S)
unnamed: R1_BAT.2, U1.1 (STAT)
unnamed: CHG_LED.C, R1_BAT.1
unnamed: EPD_C1.1, J3.4
unnamed: R2_BAT.2, U1.5 (PROG)
unnamed: EPD_C2.1, J3.5
unnamed: C44.1, D3.2 (A), D4.1 (K)
unnamed: J1.A5, R2-USB1.2
unnamed: C4.1, IC2.5 (CT)
unnamed: EPD_C6.1, J3.18
unnamed: EPD_C7.1, J3.19
unnamed: EPD_C8.1, J3.20
unnamed: EPD_C10.1, J3.22
unnamed: EPD_C12.1, J3.24
unnamed: D6.1 (CATHODE), R_CAPACITOR.1
PREVGH: D5.1 (K), EPD_C9.1, J3.21
PREVGL: D4.2 (A), EPD_C11.1, J3.23
RESE: J3.3, Q2.2 (S), R3.2
RESE': R2.2, R3.1, SJ1.2
RESET: C5.1, IC2.1 (VOUT), RESET_BUTTON.3, RESET_BUTTON.4, R_RESET.1, R_RESET.2, U2.3 (EN)
RTC_RST: U2.16 (IO18), U6.4 (!RST)
RX: TP2_RX.TP, U2.24 (RXD0/GPIO17)
SCK: D9.2, J2.P5 (CLK), J3.13, R13.1, TP8_SCK.TP, U2.6 (IO6), U5.6 (CLK)
SCL: J4.4, R5.1, U2.20 (IO22), U3.4 (SCK), U4.7 (SCL), U6.16 (SCL)
SDA: J4.3, R6.1, U2.19 (IO21), U3.3 (SDI), U4.8 (SDA), U6.15 (SDA)
SRC: C44.2, D5.2 (A), L1.1, Q2.3 (D)
SS_SD: D12.2, J2.P2 (CD/DAT3), R10.1, U2.4 (IO4)
TX: TP1_TX.TP, U2.25 (TXD0/GPIO16)
USB_D+: D1.1 (I/O1_1), U2.14 (IO13)
USB_D-: D1.3 (I/O2_1), U2.13 (IO12)
VBAT: C2_BAT.1, Q1.3 (D), TP3_VBAT.TP, U1.3 (VBAT), U4.2 (CELL), U4.3 (VDD)
VBUS: C1_BAT.1, C4_USB.1, C5_USB.1, CHG_LED.A, D1.5 (VBUS), D2.2 (ANODE), PFMF.050.1.2, Q1.1 (G), R1_PWRUSB.2, TP14_VBUS.TP, U1.4 (VIN)
VRTC: C8.1, C10_SUPERCAP.1, R_CAPACITOR.2, U6.14 (VBAT)
VUSB: J1.A4, J1.A9, J1.B4, J1.B9, PFMF.050.1.1

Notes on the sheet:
USB C connector & ESD protection
SD Card
LDO Voltage Regulator
Display Type Selector
E-Paper Drive Circuit
Li-Po Battery Charging Controller
ESP32 C6
E-Paper Display Header
EPD Power
Environmental Sensor BME688
Voltage Supervisor + Reset & Boot / IO Button
Battery Charge Level
RTC Module DS3231SN
Test Pads
Qwiic / Stemma QT
SPI ESD Protection Lines
External NOR Flash 64MB

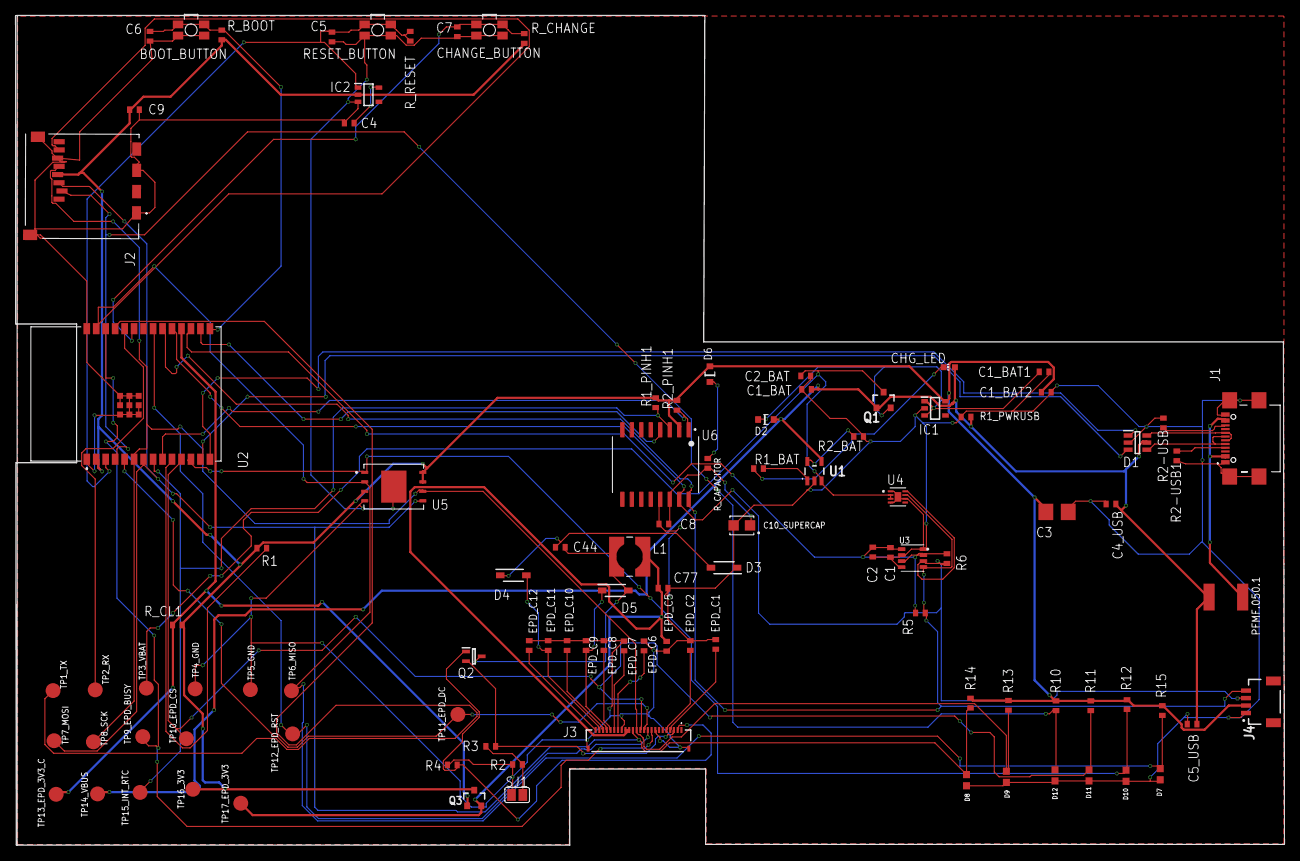
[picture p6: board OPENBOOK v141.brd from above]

Board: 2 copper layers, 170.1 x 111.2 mm, 103 parts (0 on the bottom side), 55 nets.

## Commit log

2025-04-03 Add mechanical folder
    [OPENBOOK_3D_EXPLODED.step, OPENBOOK_3D_FINAL v8.f3z]
2025-04-14 Solved issues
    [OPENBOOK_3D_EXPLODED.step, OPENBOOK_3D_FINAL.f3z]

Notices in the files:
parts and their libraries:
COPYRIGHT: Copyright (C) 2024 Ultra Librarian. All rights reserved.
